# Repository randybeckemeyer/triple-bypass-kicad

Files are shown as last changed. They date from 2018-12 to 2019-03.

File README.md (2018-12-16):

# Triple Bypass
The Triple Bypass is an audio/video mod board designed for Sega Genesis/Megadrive consoles. It contains bypass circuitry for RGBs video and also contains a Mega Amp 2.0 audio amplifier designed by Ace and Villahed94.

http://www.sega-16.com/forum/showthread.php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!

The schematic circuits are the same as db-electronics version 0.3. The schematic and layout are redrawn with as many built-in library parts as possible. The schematic is shuffled around but contains equivelant circuits with jumpers added. The board is larger than db-electronics version 0.3 and is untested.

# Install Instructions
Use the Mega Amp 2.0 thread for wire tap points on various console revisions.

# Uses Solder Jumpers instead of different Bill of Materials
This is intended to be built with a pick and place assemble line. No need for resistor kits or boards with different build options. The board is designed to be fully populated with one BOM. There are solder jumpers for attenuation resistors and to choose which sound chip your system contains.
* YM2612
* ASIC YM3438
* GOAC YM3438

# PCB Finish
There are no special requirements for the finish of this PCB - a 1.6mm PCB with HASL finish is perfectly acceptable for this PCB.

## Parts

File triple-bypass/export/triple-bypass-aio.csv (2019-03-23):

Id | Designator | Package | Quantity | Designation | Supplier and ref
1 | J1 | CUI_MD-90SM | 1 | MD-90SM
2 | U1 | TSSOP-8_3x3mm_P0.65mm | 1 | LMV358M8G-13
3 | JP7,JP14,JP4,JP8,JP12,JP11,JP10,JP9,JP3,JP2,JP1,JP13,JP6,JP5 | SolderJumper-2_P1.3mm_Open_RoundedPad1.0x1.5mm | 14 | SolderJumper_3_Open
4 | C1,C12,C2 | C_0603_1608Metric | 3 | 10uF/10V
5 | R19,R20 | R_0603_1608Metric | 2 | 120K
6 | C5,C9,C8,C6,C4,C3 | C_0603_1608Metric | 6 | 1uF/16V
7 | C17,C13 | C_0603_1608Metric | 2 | 0.1uF/50V
8 | C10,C11 | C_0603_1608Metric | 2 | 180pF/50V
9 | R16,R11 | R_0603_1608Metric | 2 | 6K19
10 | R17,R12 | R_0603_1608Metric | 2 | 43K
11 | R18,R13 | R_0603_1608Metric | 2 | 56K
12 | R21,R22 | R_0603_1608Metric | 2 | 240K
13 | R24,R23 | R_0603_1608Metric | 2 | 10K
14 | R25,R26 | R_0603_1608Metric | 2 | 332R
15 | R27,R15,R2,R1 | R_0603_1608Metric | 4 | 2K2
16 | R28,R29,R30,R31 | R_0603_1608Metric | 4 | 5K62
17 | R32,R34,R35,R33 | R_0603_1608Metric | 4 | 1K
18 | R36 | R_0603_1608Metric | 1 | 100K
19 | R37,R5,R4,R3,R6 | R_0603_1608Metric | 5 | 75R
20 | R14 | R_0603_1608Metric | 1 | 750R
21 | R10,R9,R8,R7 | R_0603_1608Metric | 4 | 130K
22 | SW3,SW2 | CL-SB-12B-01 | 2 | SW_SPDT
23 | C18 | CP_Elec_6.3x5.4_Nichicon | 1 | 220uF/10V
24 | C15,C16,C14 | CP_EIA-3216-18_Kemet-A_Pad1.58x1.35mm_HandSolder | 3 | 22uF/10V
25 | FD3,FD2,FD1 | Fiducial_0.5mm_Dia_1mm_Outer | 3 | Fiducial
26 | U2 | TSSOP-14_4.4x5mm_P0.65mm | 1 | THS7374IPWR
27 | P11,P5,P4,P3,P1,P2,P13,P6,P7,P8,P9,P12,P10 | TestPoint_Pad_1.5x1.5mm | 13 | TP_50
28 | LOGO1 | OSHW-Logo2_7.3x6mm_SilkScreen | 1 | Logo_Open_Hardware_Small

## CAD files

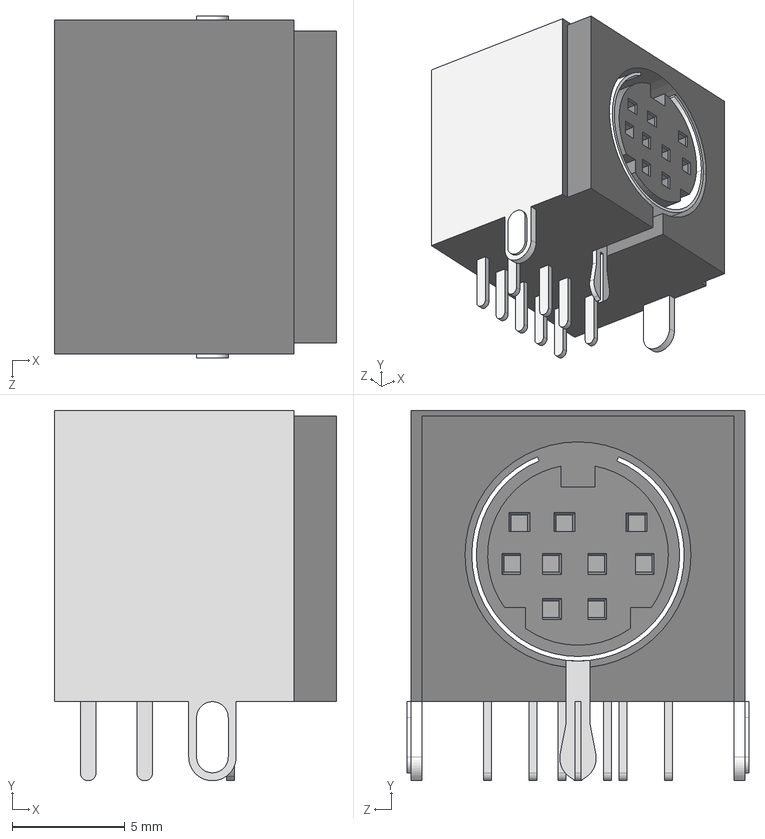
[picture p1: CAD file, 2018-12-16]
triple-bypass/CUI_MD-90SM.step
12.5 x 16.4 x 15.1 mm

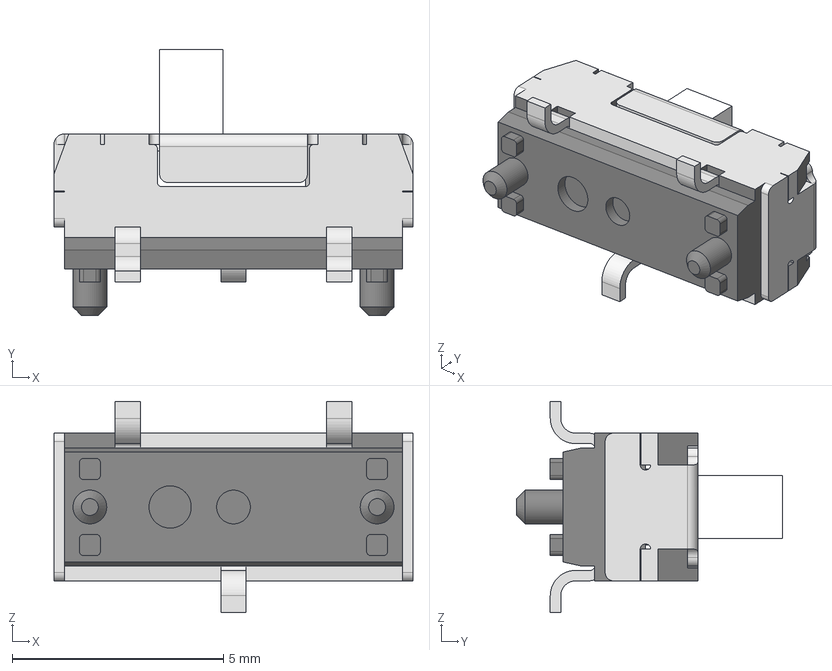
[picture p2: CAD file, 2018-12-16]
triple-bypass/CL-SB-12B-01T.stp
8.50 x 6.30 x 5.00 mm
_12B-01_c
_2Top setting_s

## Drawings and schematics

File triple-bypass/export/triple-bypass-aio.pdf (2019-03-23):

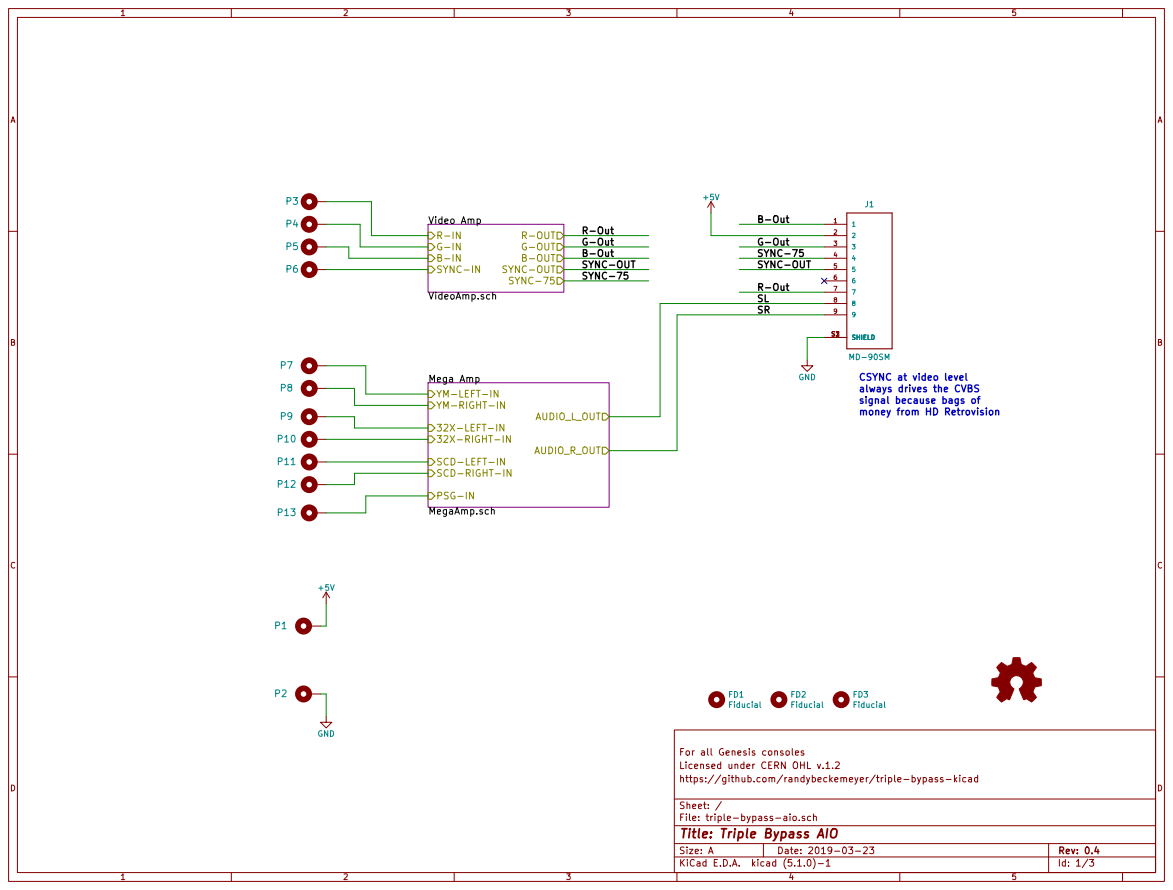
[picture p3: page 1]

CSYNC at video level
always drives the CVBS
signal because bags of
money from HD Retrovision

File: triple-bypass-aio.sch Sheet: / https://github.com/randybeckemeyer/triple-bypass-kicad

Id: 1/3 Title: Triple Bypass AIO

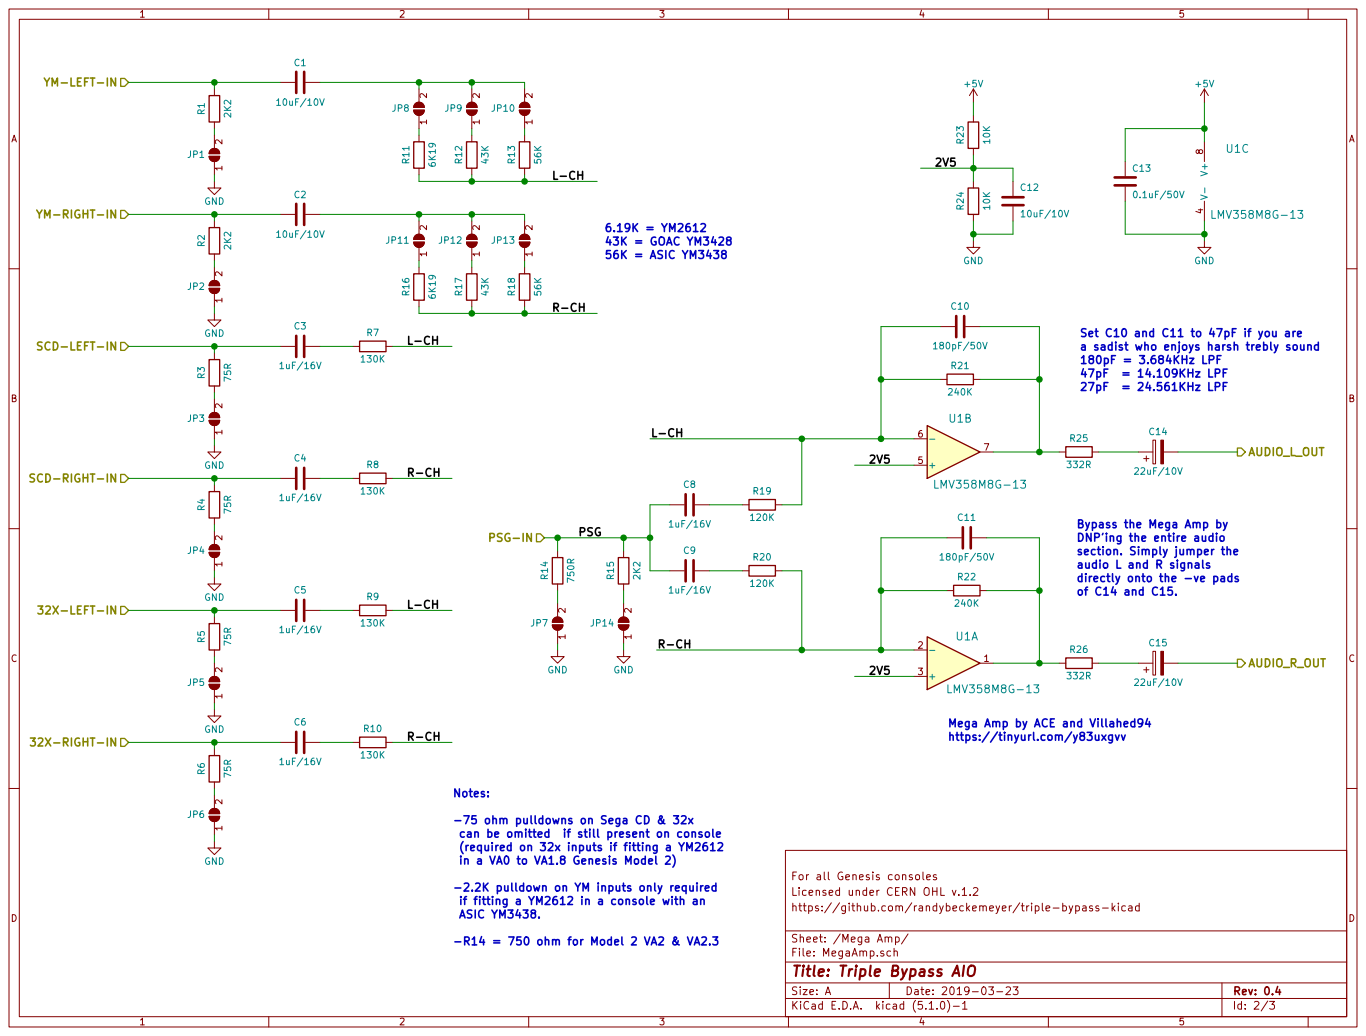
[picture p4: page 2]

Set C10 and C11 to 47pF if you are
a sadist who enjoys harsh trebly sound
180pF = 3.684KHz LPF

Bypass the Mega Amp by
DNP'ing the entire audio
section. Simply jumper the
audio L and R signals
directly onto the -ve pads

Mega Amp by ACE and Villahed94
https://tinyurl.com/y83uxgvv

-75 ohm pulldowns on Sega CD & 32x
can be omitted if still present on console
(required on 32x inputs if fitting a YM2612
in a VA0 to VA1.8 Genesis Model 2)

Licensed under CERN OHL v.1.2 For all Genesis consoles

-2.2K pulldown on YM inputs only required
if fitting a YM2612 in a console with an
ASIC YM3438. -R14 = 750 ohm for Model 2 VA2 & VA2.3

https://github.com/randybeckemeyer/triple-bypass-kicad

Rev: 0.4 | D Date: 2019-03-23 KiCad E.D.A. kicad (5.1.0)-1 Size: A

Sheet: /Mega Amp/
File: MegaAmp.sch
Id: 2/3 Title: Triple Bypass AIO

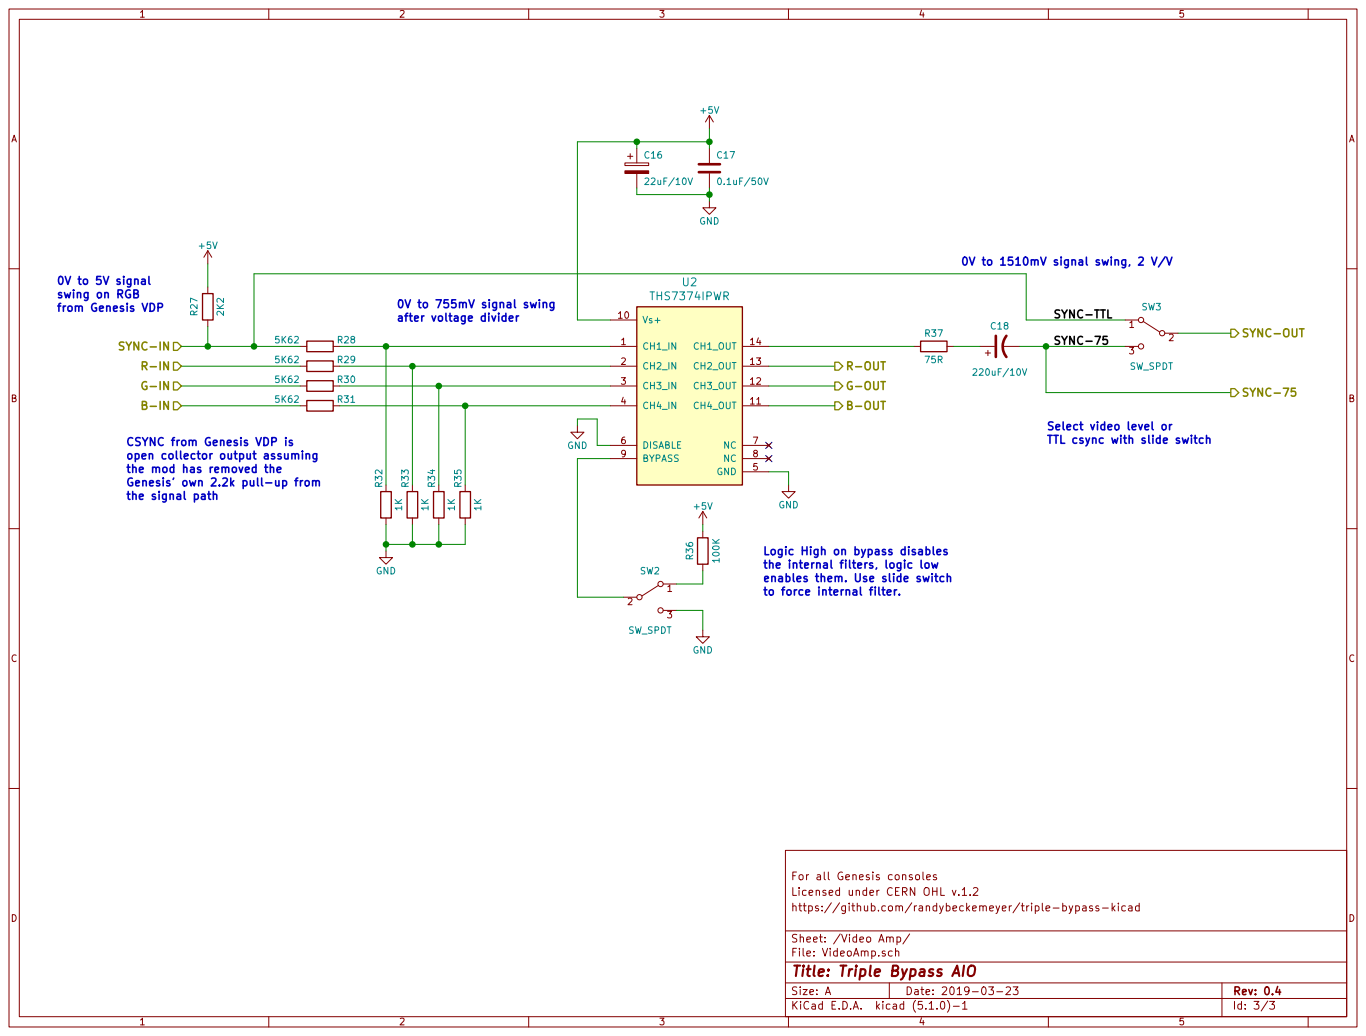
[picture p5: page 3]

TTL csync with slide switch

CSYNC from Genesis VDP is
open collector output assuming the mod has removed the Genesis' own 2.2k pull-up from

Logic High on bypass disables

Licensed under CERN OHL v.1.2 For all Genesis consoles

https://github.com/randybeckemeyer/triple-bypass-kicad

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

Sheet: /Video Amp/
File: VideoAmp.sch
Id: 3/3 Title: Triple Bypass AIO

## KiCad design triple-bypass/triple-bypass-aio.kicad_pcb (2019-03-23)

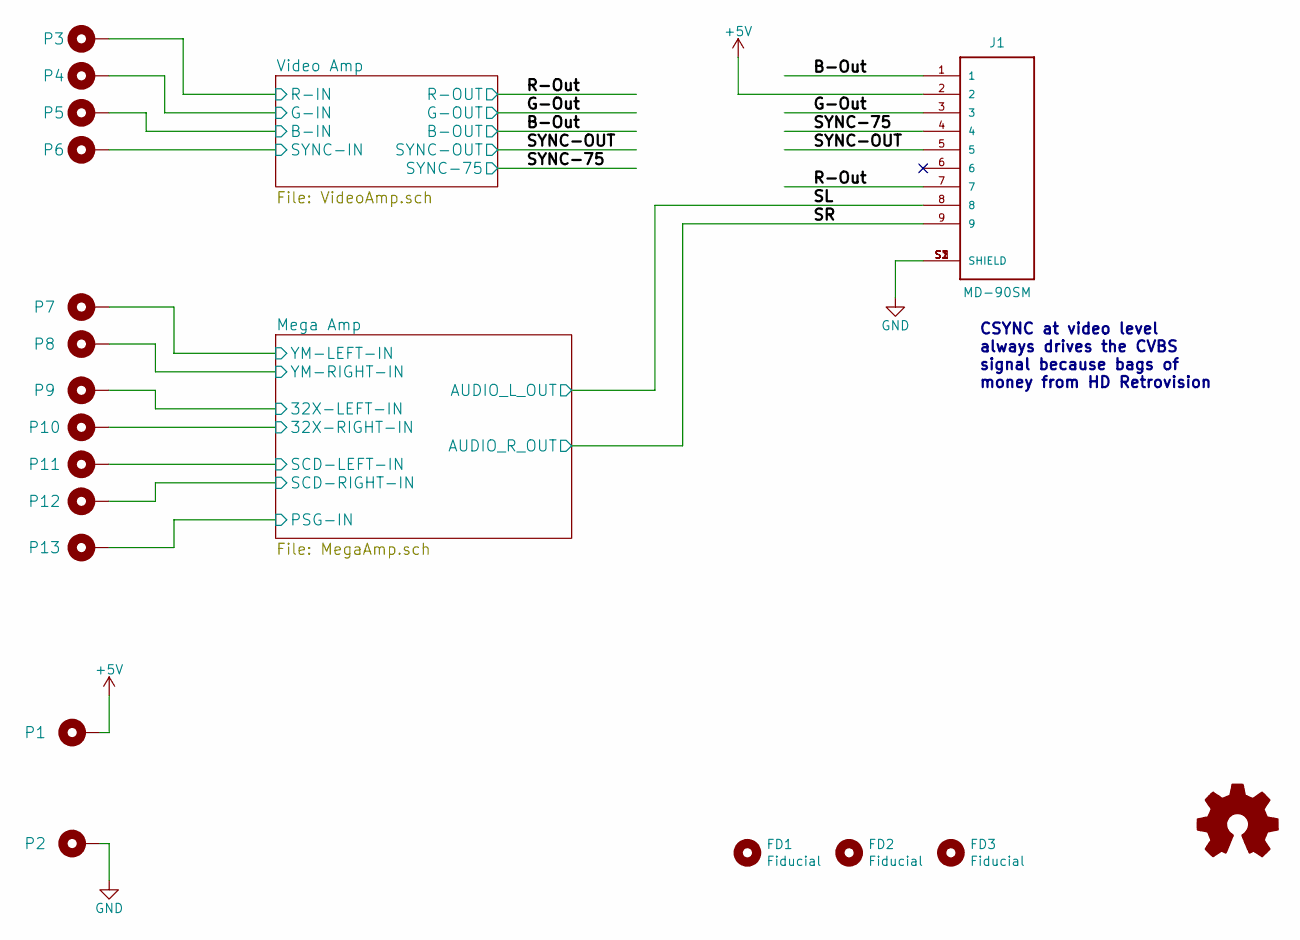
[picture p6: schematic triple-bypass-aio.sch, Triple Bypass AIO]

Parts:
FD1, FD2, FD3: Fiducial; Fiducial_0.5mm_Dia_1mm_Outer
J1: MD-90SM; CUI_MD-90SM; Digikey CP-2290-ND
LOGO1: Logo_Open_Hardware_Small; OSHW-Logo2_7.3x6mm_SilkScreen
P1, P2, P3, P4, P5, P6, P7, P8, P9, P10, P11, P12, P13: TP_50; TestPoint_Pad_1.5x1.5mm; Digikey #ND

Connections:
+5V: J1.2, P1.1; also elsewhere on the board
/B-Out: J1.1; also elsewhere on the board
/G-Out: J1.3; also elsewhere on the board
/Mega Amp/32X-LEFT-IN: P9.1; also elsewhere on the board
/Mega Amp/32X-RIGHT-IN: P10.1; also elsewhere on the board
/Mega Amp/PSG-IN: P13.1; also elsewhere on the board
/Mega Amp/SCD-LEFT-IN: P11.1; also elsewhere on the board
/Mega Amp/SCD-RIGHT-IN: P12.1; also elsewhere on the board
/Mega Amp/YM-LEFT-IN: P7.1; also elsewhere on the board
/Mega Amp/YM-RIGHT-IN: P8.1; also elsewhere on the board
/R-Out: J1.7; also elsewhere on the board
/SL: J1.8; also elsewhere on the board
/SR: J1.9; also elsewhere on the board
/SYNC-75: J1.4; also elsewhere on the board
/SYNC-OUT: J1.5; also elsewhere on the board
/Video Amp/B-IN: P5.1; also elsewhere on the board
/Video Amp/G-IN: P4.1; also elsewhere on the board
/Video Amp/R-IN: P3.1; also elsewhere on the board
/Video Amp/SYNC-IN: P6.1; also elsewhere on the board
GND: J1.S1 (SHIELD), J1.S2 (SHIELD), J1.S3 (SHIELD), P2.1; also elsewhere on the board

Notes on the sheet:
CSYNC at video level always drives the CVBS signal because bags of money from HD Retrovision

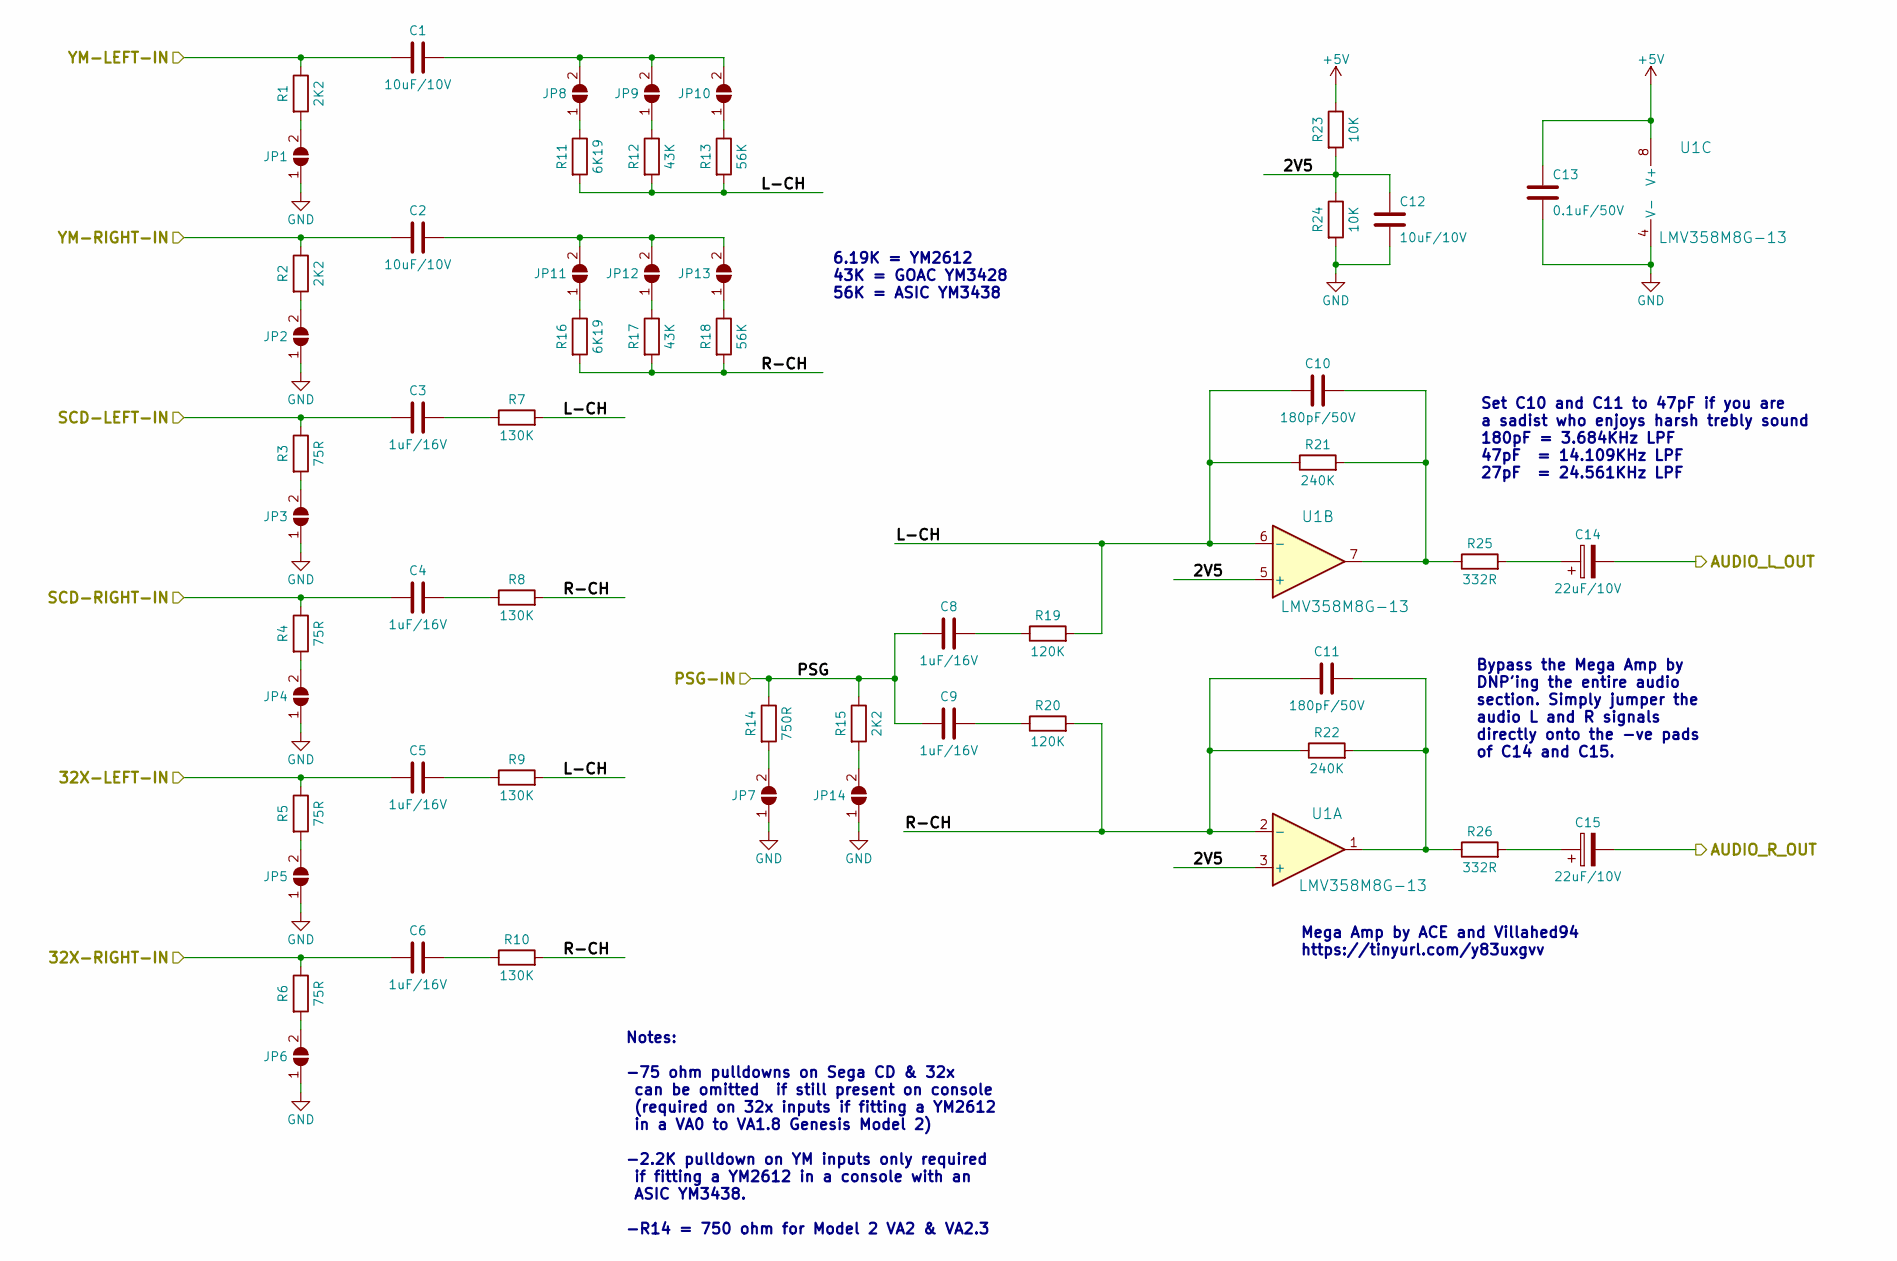
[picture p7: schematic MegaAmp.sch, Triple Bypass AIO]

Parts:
C1, C2, C12: 10uF/10V; C_0603_1608Metric; Digikey 478-10766-1-ND
C3, C4, C5, C6, C8, C9: 1uF/16V; C_0603_1608Metric; Digikey 445-1416-1-ND
C10, C11: 180pF/50V; C_0603_1608Metric; Digikey 311-4096-6-ND
C13: 0.1uF/50V; C_0603_1608Metric; Digikey 445-5666-1-ND
C14, C15: 22uF/10V; CP_EIA-3216-18_Kemet-A_Pad1.58x1.35mm_HandSolder; Digikey 478-1663-1-ND
JP1, JP2, JP3, JP4, JP5, JP6, JP7, JP8, JP9, JP10, JP11, JP12, JP13, JP14: SolderJumper_3_Open; SolderJumper-2_P1.3mm_Open_RoundedPad1.0x1.5mm
R1, R2, R15: 2K2; R_0603_1608Metric; Digikey P2.20KHCT-ND
R3, R4, R5, R6: 75R; R_0603_1608Metric; Digikey P75.0HCT-ND
R7, R8, R9, R10: 130K; R_0603_1608Metric; Digikey P130KHCT-ND
R11, R16: 6K19; R_0603_1608Metric; Digikey P6.19KHCT-ND
R12, R17: 43K; R_0603_1608Metric; Digikey P43.0KHCT-ND
R13, R18: 56K; R_0603_1608Metric; Digikey P56.0KHCT-ND
R14: 750R; R_0603_1608Metric; Digikey P750HCT-ND
R19, R20: 120K; R_0603_1608Metric; Digikey P120KHCT-ND
R21, R22: 240K; R_0603_1608Metric; Digikey P240KHCT-ND
R23, R24: 10K; R_0603_1608Metric; Digikey P10.0KHCT-ND
R25, R26: 332R; R_0603_1608Metric; Digikey P332HCT-ND
U1: LMV358M8G-13; TSSOP-8_3x3mm_P0.65mm; Digikey LMV358M8G-13DITR-ND

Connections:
+5V: C13.1, R23.1, U1.8 (V+); also elsewhere on the board
/Mega Amp/2V5: C12.2, R23.2, R24.1, U1.3 (+), U1.5 (+)
/Mega Amp/32X-LEFT-IN: C5.1, R5.1; also elsewhere on the board
/Mega Amp/32X-RIGHT-IN: C6.1, R6.1; also elsewhere on the board
/Mega Amp/L-CH: C10.1, R7.2, R9.2, R11.2, R12.2, R13.2, R19.2, R21.1, U1.6 (-)
/Mega Amp/PSG-IN: C8.1, C9.1, R14.1, R15.1; also elsewhere on the board
/Mega Amp/R-CH: C11.1, R8.2, R10.2, R16.2, R17.2, R18.2, R20.2, R22.1, U1.2 (-)
/Mega Amp/SCD-LEFT-IN: C3.1, R3.1; also elsewhere on the board
/Mega Amp/SCD-RIGHT-IN: C4.1, R4.1; also elsewhere on the board
/Mega Amp/YM-LEFT-IN: C1.2, R1.1; also elsewhere on the board
/Mega Amp/YM-RIGHT-IN: C2.2, R2.1; also elsewhere on the board
/SL: C14.2; also elsewhere on the board
/SR: C15.2; also elsewhere on the board
GND: C12.1, C13.2, JP1.1 (A), JP2.1 (A), JP3.1 (A), JP4.1 (A), JP5.1 (A), JP6.1 (A), JP7.1 (A), JP14.1 (A), R24.2, U1.4 (V-); also elsewhere on the board
unnamed: C1.1, JP8.2 (B), JP9.2 (B), JP10.2 (B)
unnamed: C2.1, JP11.2 (B), JP12.2 (B), JP13.2 (B)
unnamed: C3.2, R7.1
unnamed: C4.2, R8.1
unnamed: C5.2, R9.1
unnamed: C6.2, R10.1
unnamed: C8.2, R19.1
unnamed: C9.2, R20.1
unnamed: C10.2, R21.2, R25.1, U1.7
unnamed: C11.2, R22.2, R26.1, U1.1
unnamed: C14.1, R25.2
unnamed: C15.1, R26.2
unnamed: JP1.2 (B), R1.2
unnamed: JP2.2 (B), R2.2
unnamed: JP3.2 (B), R3.2
unnamed: JP4.2 (B), R4.2
unnamed: JP5.2 (B), R5.2
unnamed: JP6.2 (B), R6.2
unnamed: JP7.2 (B), R14.2
unnamed: JP8.1 (A), R11.1
unnamed: JP9.1 (A), R12.1
unnamed: JP10.1 (A), R13.1
unnamed: JP11.1 (A), R16.1
unnamed: JP12.1 (A), R17.1
unnamed: JP13.1 (A), R18.1
unnamed: JP14.2 (B), R15.2

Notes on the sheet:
Mega Amp by ACE and Villahed94 https://tinyurl.com/y83uxgvv
Set C10 and C11 to 47pF if you are a sadist who enjoys harsh trebly sound 180pF = 3.684KHz LPF 47pF = 14.109KHz LPF 27pF = 24.561KHz LPF
Bypass the Mega Amp by DNP'ing the entire audio section. Simply jumper the audio L and R signals directly onto the -ve pads of C14 and C15.
Notes: -75 ohm pulldowns on Sega CD & 32x can be omitted if still present on console (required on 32x inputs if fitting a YM2612 in a VA0 to VA1.8 Genesis Model 2) -2.2K pulldown on YM inputs only required if fitting a YM2612 in a console with an ASIC YM3438. -R14 = 750 ohm for Model 2 VA2 & VA2.3
6.19K = YM2612 43K = GOAC YM3428 56K = ASIC YM3438

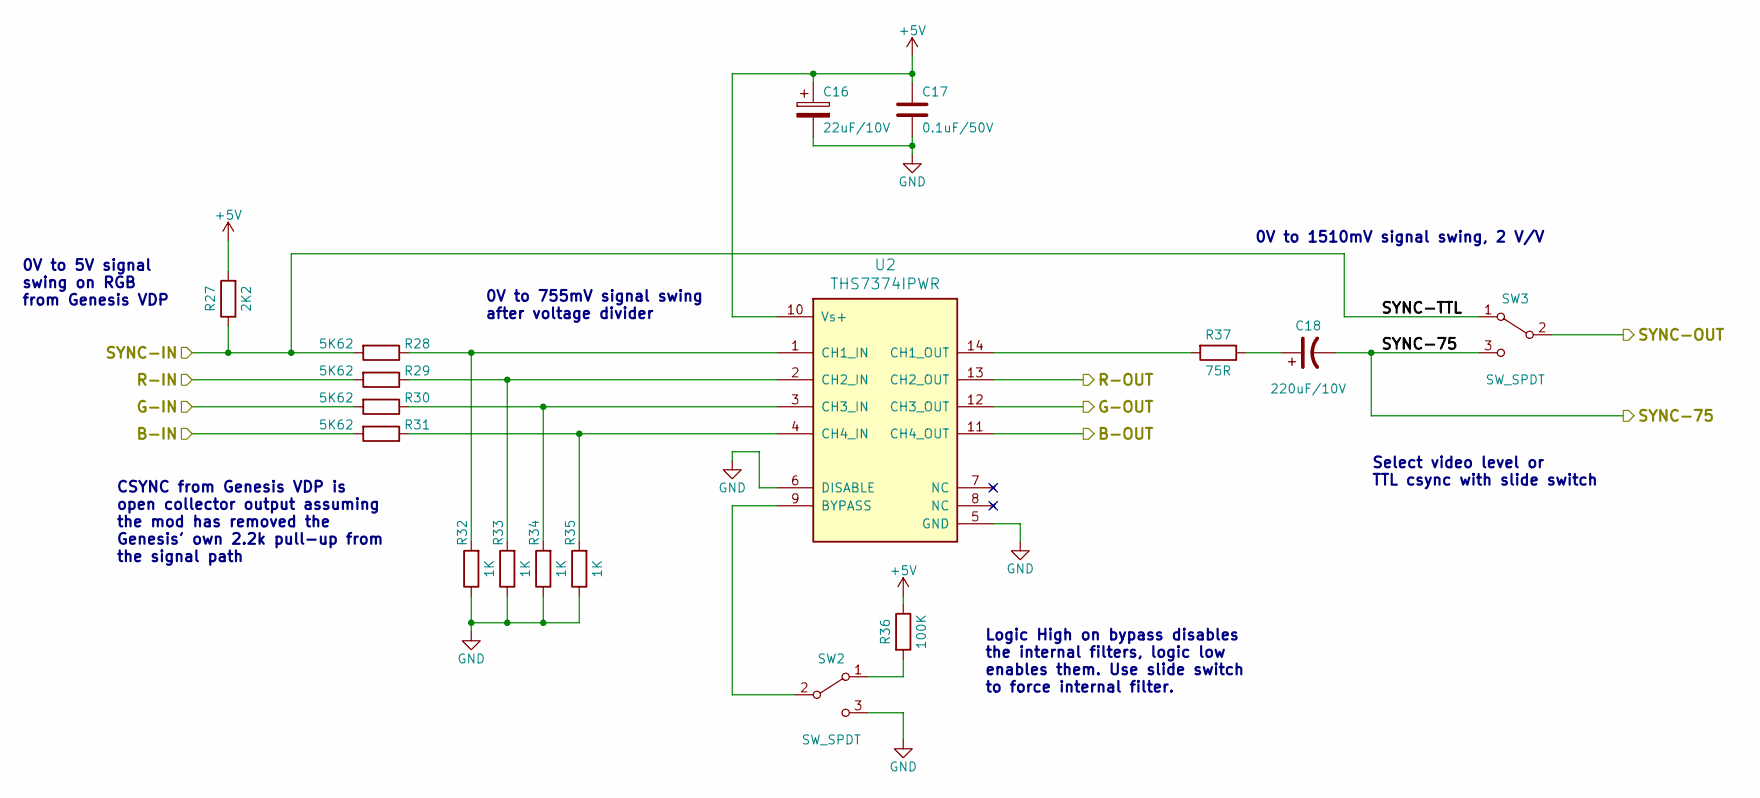
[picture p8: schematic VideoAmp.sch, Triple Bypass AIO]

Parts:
C16: 22uF/10V; CP_EIA-3216-18_Kemet-A_Pad1.58x1.35mm_HandSolder; Digikey 478-1663-1-ND
C17: 0.1uF/50V; C_0603_1608Metric; Digikey 445-5666-1-ND
C18: 220uF/10V; CP_Elec_6.3x5.4_Nichicon; Digikey 493-6210-1-ND
R27: 2K2; R_0603_1608Metric; Digikey P2.20KHCT-ND
R28, R29, R30, R31: 5K62; R_0603_1608Metric; Digikey P5.62KHCT-ND
R32, R33, R34, R35: 1K; R_0603_1608Metric; Digikey P1.00KHCT-ND
R36: 100K; R_0603_1608Metric; Digikey RHM100KAYCT-ND
R37: 75R; R_0603_1608Metric; Digikey P75.0HCT-ND
SW2, SW3: SW_SPDT; CL-SB-12B-01; Digikey 563-1318-1-ND
U2: THS7374IPWR; TSSOP-14_4.4x5mm_P0.65mm; Digikey 296-41661-1-ND

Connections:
+5V: C16.1, C17.1, R27.2, R36.1, U2.10 (Vs+); also elsewhere on the board
/B-Out: U2.11 (CH4_OUT); also elsewhere on the board
/G-Out: U2.12 (CH3_OUT); also elsewhere on the board
/R-Out: U2.13 (CH2_OUT); also elsewhere on the board
/SYNC-75: C18.2, SW3.3 (C); also elsewhere on the board
/SYNC-OUT: SW3.2 (B); also elsewhere on the board
/Video Amp/B-IN: R31.2; also elsewhere on the board
/Video Amp/G-IN: R30.2; also elsewhere on the board
/Video Amp/R-IN: R29.2; also elsewhere on the board
/Video Amp/SYNC-IN: R27.1, R28.2, SW3.1 (A); also elsewhere on the board
GND: C16.2, C17.2, R32.1, R33.1, R34.1, R35.1, SW2.3 (C), U2.5 (GND), U2.6 (DISABLE); also elsewhere on the board
unnamed: C18.1, R37.1
unnamed: R28.1, R32.2, U2.1 (CH1_IN)
unnamed: R29.1, R33.2, U2.2 (CH2_IN)
unnamed: R30.1, R34.2, U2.3 (CH3_IN)
unnamed: R31.1, R35.2, U2.4 (CH4_IN)
unnamed: R36.2, SW2.1 (A)
unnamed: R37.2, U2.14 (CH1_OUT)
unnamed: SW2.2 (B), U2.9 (BYPASS)

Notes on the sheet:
Logic High on bypass disables the internal filters, logic low enables them. Use slide switch to force internal filter.
Select video level or TTL csync with slide switch
0V to 5V signal swing on RGB from Genesis VDP
0V to 755mV signal swing after voltage divider
CSYNC from Genesis VDP is open collector output assuming the mod has removed the Genesis' own 2.2k pull-up from the signal path
0V to 1510mV signal swing, 2 V/V

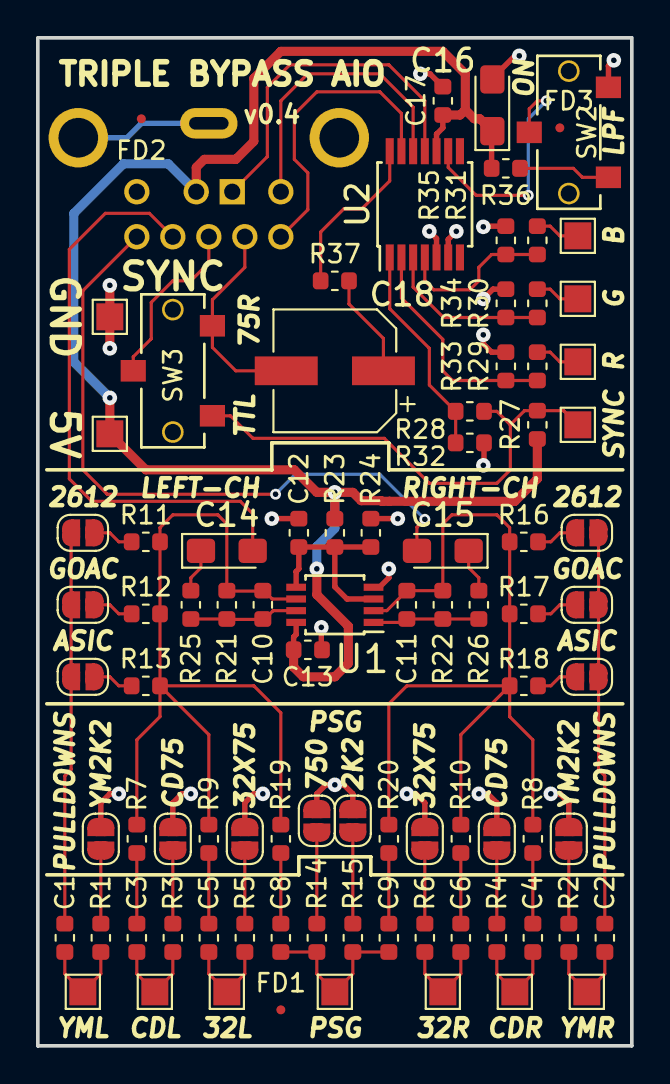
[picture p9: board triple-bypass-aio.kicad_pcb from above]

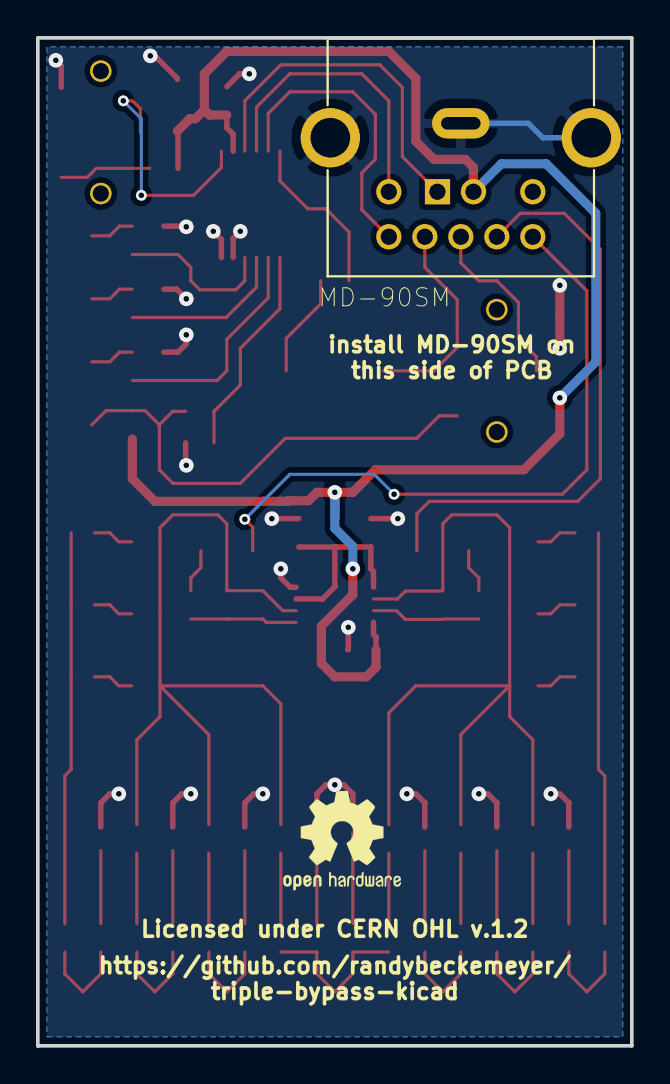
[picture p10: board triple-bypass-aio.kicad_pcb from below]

Board: 2 copper layers, 33.0 x 56.0 mm, 90 parts (2 on the bottom side), 57 nets.

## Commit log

2018-12-16 Organize and export pdf
    [VideoAmp.sch, triple-bypass.kicad_pcb, triple-bypass.sch]
2018-12-17 Increase 5V rail width
    [VideoAmp.sch, triple-bypass.kicad_pcb, triple-bypass.sch]
2019-03-23 Rename to AIO
    Moved offset of PCB so footprints are on grid. Saved in KiCad version 5.1.0. Export gerbers. Found and deleted board cuts in MiniDIN footprint.
    [MegaAmp.sch, VideoAmp.sch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]
